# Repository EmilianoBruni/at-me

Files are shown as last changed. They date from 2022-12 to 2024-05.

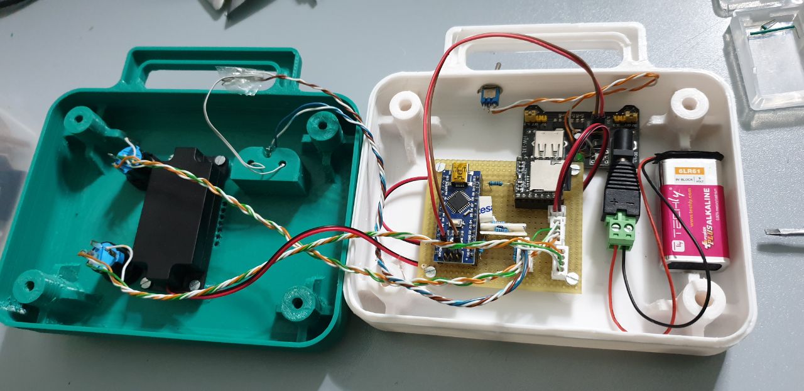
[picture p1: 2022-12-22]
Releases/00.01/photo_2022-12-22_20-16-52.jpg

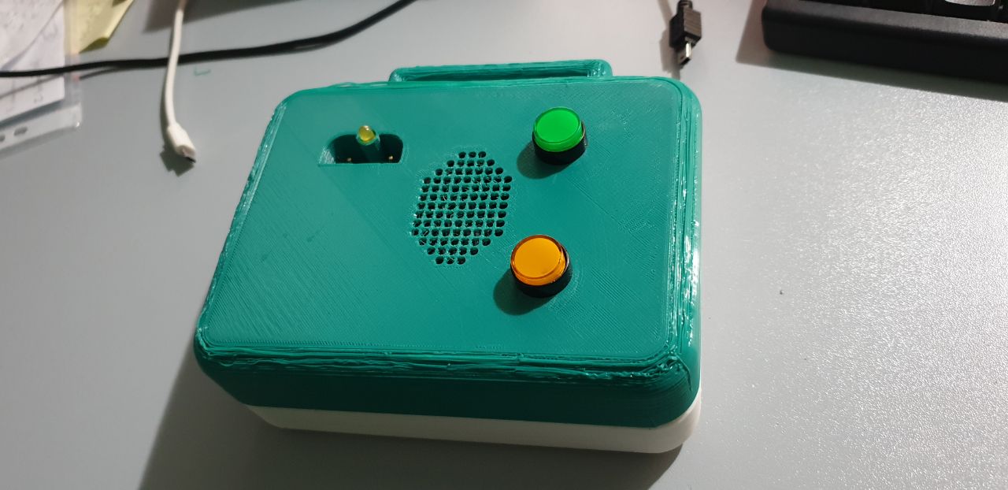
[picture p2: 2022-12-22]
Releases/00.01/photo_2022-12-22_20-16-48.jpg

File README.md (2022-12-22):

# at-me - AED Trainer made easy

## Build an AED trainer by youself

This is a hands made AED Trainer build with 

- Arduino nano, 
- DFPlayer Mini from DFRobot 
- some minor components.

The circuit is developed using Fritzing and is powered by a 9V battery, the code with Visual Code, the box with Autodesk Fusion 360 and printed with a Geeetek A20.

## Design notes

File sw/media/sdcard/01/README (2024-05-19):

Created with https://ttsfree.com/text-to-speech/italian, TTS Server 2, 100 Italian - Female - (Isabella), Voice Pitch -5%, Speed 0

02 - 1 sec@1800Hz CB128k Amplitude 0.3
10 - Applicare le placche sul torace nudo del paziente
11 - Collegare il connettore delle placche vicino la spia lampeggiante
12 - Analisi del ritmo cardiaco in corso, non toccare il paziente
13 - Scarica non consiglia, se necessario continuare con la rianimazione cardio polmonare
14 - Scarica consigliata. Carica in corso.
15 - Erogare la scarica adesso. Premere il pulsante arancione (repeated 4 times) (mix with 16)
16 - 60 sec@1800Hz CB128k Amplitude 0.1
18 - Scarica erogata
19 - Pulsante di scarica non premuto. Scarica annullata.
20 - Scarica non necessaria.
25 - Applicare le placche e dopo inserire il connettore
26 - Premere con decisione le placche sul torace nudo del paziente e dopo inserire il connettore saldamente
98 - 0.15 sec@2000Hz CB128k Amplitude 0.3
99 - In pausa. Se necessario, ricominciare con la rianimazione cardiopolmonare.

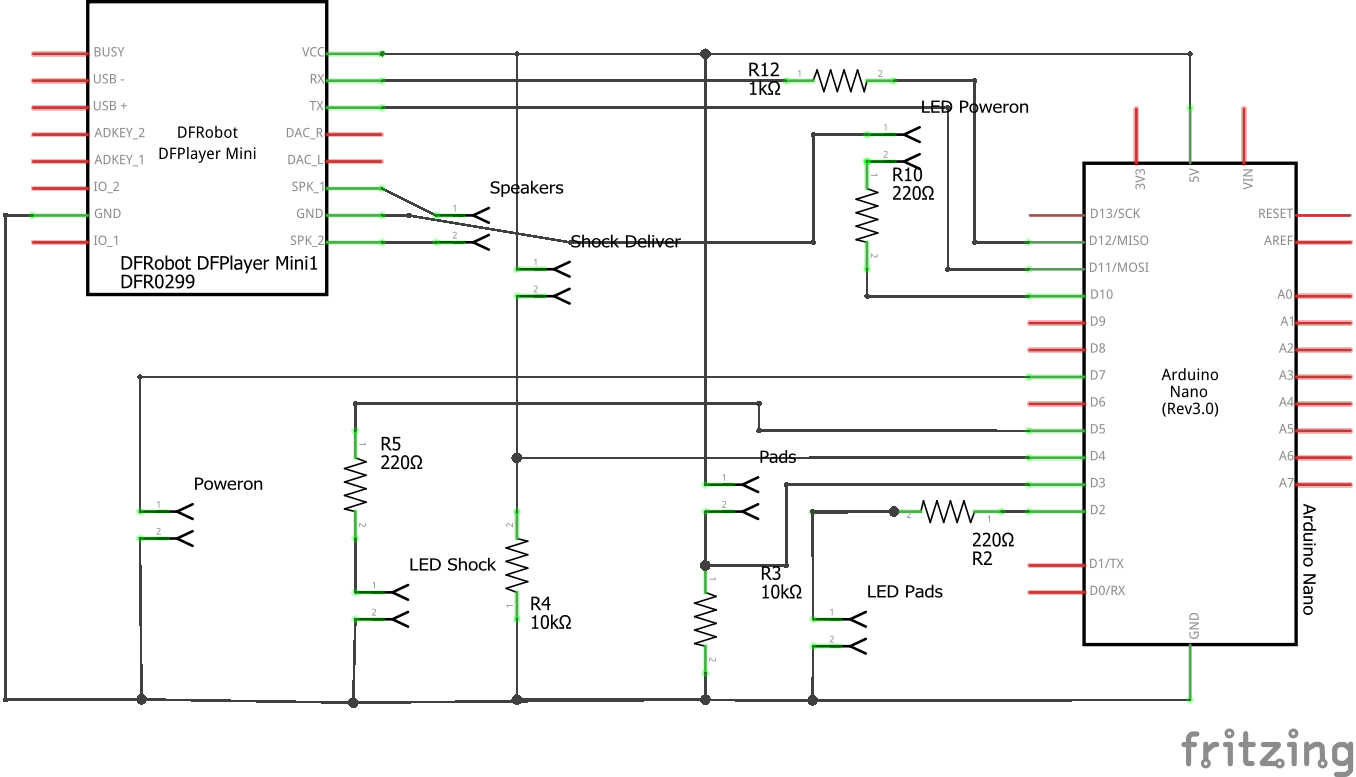
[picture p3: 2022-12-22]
Releases/00.01/schema.png

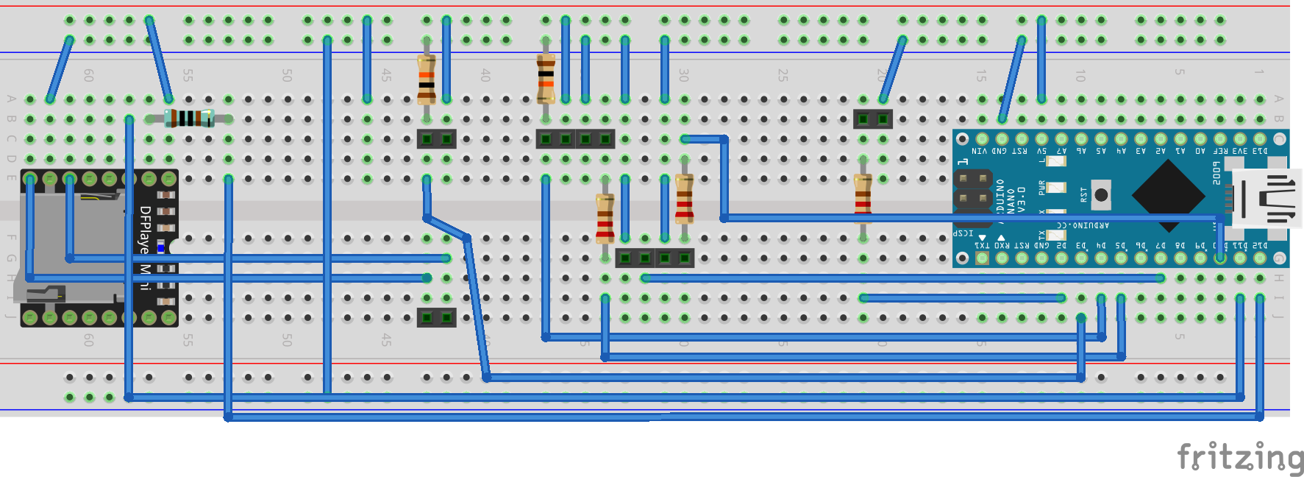
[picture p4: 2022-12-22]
Releases/00.01/breadboard.png

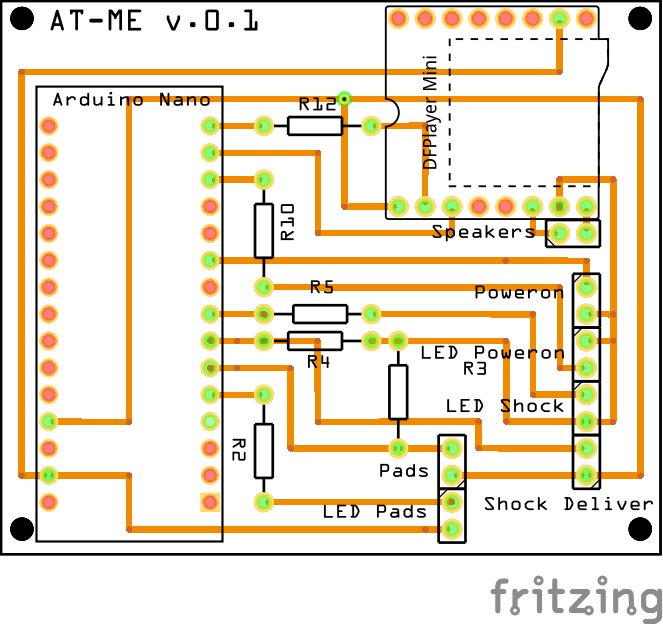
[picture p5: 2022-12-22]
Releases/00.01/pcb.png

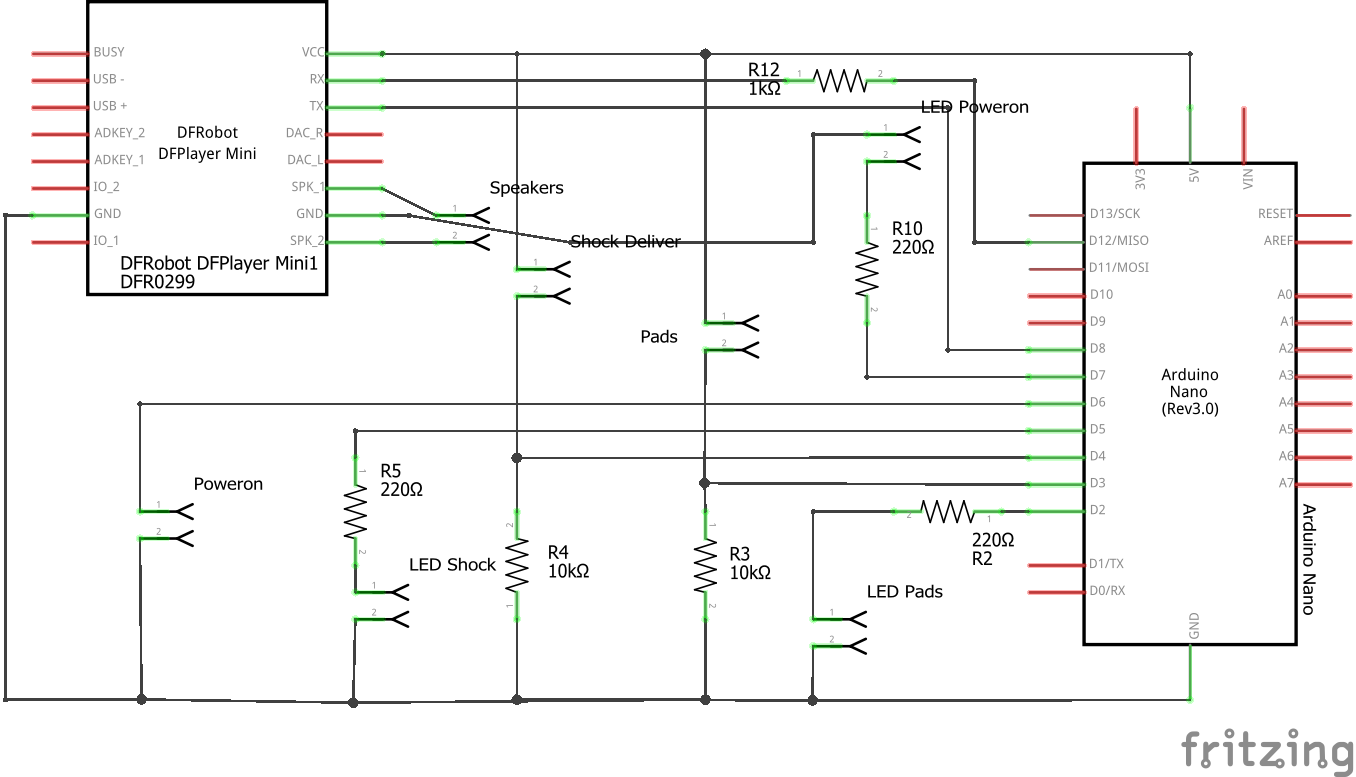
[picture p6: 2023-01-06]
Releases/00.02/schema.png

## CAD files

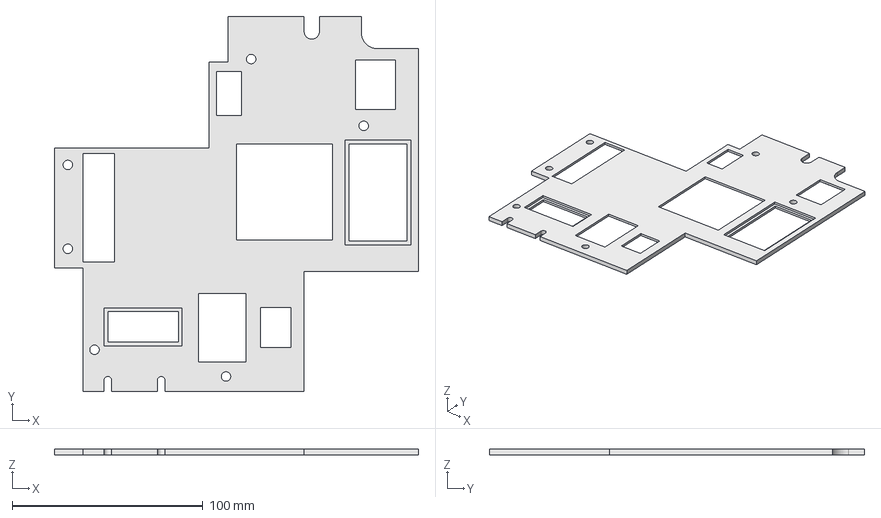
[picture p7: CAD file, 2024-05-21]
cad/Laerdal FR2 Trainer - PCB.FCStd
191.0 x 197.0 x 3.00 mm

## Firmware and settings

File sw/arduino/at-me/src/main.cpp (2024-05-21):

#include <Arduino.h>
#include <SoftwareSerial.h>
#include <DFRobotDFPlayerMini.h>
#include <Aed.h>
#include <Admin.h>
#include <OneButton.h>

#define APP_NAME           "at-me"
#define APP_VER_MAJOR      0
#define APP_VER_MINOR      6

#define SND_LANG_IT        1
#define TEST_BOARD         false
#define PADS_LED_ID        2
#define PADS_BTN_ID        3
#define SHOCK_BUTTON_ID    4
#define SHOCK_LED_ID       5
#define POWER_BUTTON_ID    6
#define POWER_LED_ID       7
#define SW_SERIAL_RX_ID    8
// in old PCB version < 0.6, TX is 12, in new PCB version, TX is 9
#define SW_SERIAL_TX_ID    APP_VER_MINOR < 6 ? 12 : 9
// in PCB version 0.5, SETUP_TOP_BTN_ID is 9, in new PCB version, SETUP_TOP_BTN_ID is 10
#define SETUP_TOP_BTN_ID   APP_VER_MINOR == 5 ? 9 : 10
// in PCB version 0.5, SETUP_BTM_BTN_ID is 10, in new PCB version, SETUP_BTM_BTN_ID is 11
#define SETUP_BTM_BTN_ID   APP_VER_MINOR == 5 ? 10 : 11

#define BTN_POWER          0
#define BTN_PADS           1
#define BTN_SHOCK          2
#define BTN_SETUP_TOP      3
#define BTN_SETUP_BTM      4

#define POWER_BUTTON_DELAY 500 // press powerButton for 0.5s
//const int           DEBUG_LED_ID       = LED_BUILTIN;


void serialInit();
void digitalInputInit();
void buttonInit();
void buttonLoop();
void powerStateUpdate();
void playerInit();
void aedInit();
void adminInit();
byte getLang();
void testBoard();

//bool                powerState = false; // AED is on/off
bool                audioState = false; // player well initialized?

SoftwareSerial      mSwSerial(SW_SERIAL_RX_ID,SW_SERIAL_TX_ID);
DFRobotDFPlayerMini mPlayer;
Aed*                mAed;
Admin*              mAdmin;
OneButton           mButtons[5];

void setup() {
    serialInit();
    digitalInputInit();
    buttonInit();   // setup OneButton buttons support
    playerInit();
    aedInit();
    adminInit();
    if (TEST_BOARD) {
        Serial.println("Test Board Mode ON");
    }
}

void loop() {
    buttonLoop();
    if (TEST_BOARD) {
        testBoard();
        return;
    }
    powerStateUpdate();
    if (mAed->getState() > PowerOff) {
        mAed->loop();
    }  else {
        // this is required to allow setVolume buttons (setup_top an setup_btm) to work
        if (mPlayer.available()) { mPlayer.readType(); }
    }
    if (mAdmin->getState() > PowerOff) mAdmin->loop();
}

void aedInit() {
    mAed = new Aed(getLang(), mPlayer, POWER_LED_ID, PADS_BTN_ID,PADS_LED_ID,
                   SHOCK_BUTTON_ID,SHOCK_LED_ID);
}

void adminInit() {
    mAdmin = new Admin(getLang(), mPlayer);
}


void serialInit() {
    Serial.begin(115200);

    Serial.println();
    Serial.println("This is " + String(APP_NAME) + " ver. " + APP_VER_MAJOR +
                   '.' + APP_VER_MINOR +
                   " - Copyright (c) 2022 - Emiliano Bruni <info@ebruni.it>");
}

void digitalInputInit() {
    // TODO: Remove after full implementation of OneButton
    pinMode(POWER_BUTTON_ID, INPUT_PULLUP);
    pinMode(SHOCK_BUTTON_ID, INPUT_PULLUP);
    pinMode(PADS_BTN_ID, INPUT_PULLUP);

    pinMode(POWER_LED_ID, OUTPUT);
    pinMode(PADS_LED_ID, OUTPUT);
    pinMode(SHOCK_LED_ID, OUTPUT);
}

void buttonInit() {
    mButtons[BTN_POWER] = OneButton(POWER_BUTTON_ID, true, true);
    mButtons[BTN_POWER].attachClick([]() {
        Serial.println("Power Button Clicked");
    });
    mButtons[BTN_POWER].attachDoubleClick([]() {
        Serial.println("Power Button Double Clicked");
    });
    mButtons[BTN_POWER].attachLongPressStart([]() {
        Serial.println("Power Button Long Press Start");
    });
    mButtons[BTN_POWER].attachLongPressStop([]() {
        Serial.println("Power Button Long Press Stop");
    });

    mButtons[BTN_PADS] = OneButton(PADS_BTN_ID, false, false);
    mButtons[BTN_PADS].attachClick([]() {
        Serial.println("Pads Button Clicked");
    });
    mButtons[BTN_PADS].attachDoubleClick([]() {
        Serial.println("Pads Button Double Clicked");
    });
    mButtons[BTN_PADS].attachLongPressStart([]() {
        Serial.println("Pads Button Long Press Start");
    });
    mButtons[BTN_PADS].attachLongPressStop([]() {
        Serial.println("Pads Button Long Press Stop");
    });

    mButtons[BTN_SHOCK] = OneButton(SHOCK_BUTTON_ID, true, true);
    mButtons[BTN_SHOCK].attachClick([]() {
        Serial.println("Shock Button Clicked");
    });
    mButtons[BTN_SHOCK].attachDoubleClick([]() {
        Serial.println("Shock Button Double Clicked");
    });
    mButtons[BTN_SHOCK].attachLongPressStart([]() {
        Serial.println("Shock Button Long Press Start");
    });
    mButtons[BTN_SHOCK].attachLongPressStop([]() {
        Serial.println("Shock Button Long Press Stop");
    });

    // one button for SETUP_TOP_BTN_ID
    mButtons[BTN_SETUP_TOP] = OneButton(SETUP_TOP_BTN_ID, true, true);
    mButtons[BTN_SETUP_TOP].attachClick([]() {
        Serial.println("Setup Top Button Clicked");
    });
    mButtons[BTN_SETUP_TOP].attachDoubleClick([]() {
        Serial.println("Setup Top Button Double Clicked");
    });
    mButtons[BTN_SETUP_TOP].attachLongPressStart([]() {
        Serial.println("Setup Top Button Long Press Start");
    });
    mButtons[BTN_SETUP_TOP].attachLongPressStop([]() {
        Serial.println("Setup Top Button Long Press Stop");
    });

    mButtons[BTN_SETUP_TOP].attachClick([]() {
        if (mAed->getState() == PowerOff) {
            mAdmin->volumeUp();
        }
    });

    // one button for SETUP_BTM_BTN_ID
    mButtons[BTN_SETUP_BTM] = OneButton(SETUP_BTM_BTN_ID, true, true);
    mButtons[BTN_SETUP_BTM].attachClick([]() {
        Serial.println("Setup Bottom Button Clicked");
    });
    mButtons[BTN_SETUP_BTM].attachDoubleClick([]() {
        Serial.println("Setup Bottom Button Double Clicked");
    });
    mButtons[BTN_SETUP_BTM].attachLongPressStart([]() {
        Serial.println("Setup Bottom Button Long Press Start");
    });
    mButtons[BTN_SETUP_BTM].attachLongPressStop([]() {
        Serial.println("Setup Bottom Button Long Press Stop");
    });

    mButtons[BTN_SETUP_BTM].attachClick([]() {
        if (mAed->getState() == PowerOff) {
            mAdmin->volumeDown();
        }
    });


}

void buttonLoop() {
    for (int i = 0; i < 5; i++) {
        mButtons[i].tick();
    }
}

void testBoard() {
    // mPlayer.volume(10);
    // mPlayer.playFolder(SND_LANG_IT, 2); // BEEP
    // loop through POWER_LED_ID, SHOCK_LED_ID, PADS_LED_ID
    int leds[3] = {POWER_LED_ID, SHOCK_LED_ID, PADS_LED_ID};
    for (int i = 0; i < 3; i++) {
        digitalWrite(leds[i], HIGH);
    }
    delay(2000);
    for (int i = 0; i < 3; i++) {
        digitalWrite(leds[i], LOW);
    }
    delay(2000);
}

void powerStateUpdate() {
    // last applied button state
    static int           lastApplied      = HIGH;
    // last readed button state
    static int           lastRead         = LOW;
    // last time button state changed
    static unsigned long lastChangingTime = 0;

    // read powerButton
    int current = digitalRead(POWER_BUTTON_ID);

    // If the switch changed, due to noise or pressing:
    if (current != lastRead) {
        // reset the debouncing timer
        lastChangingTime = millis();
    }

    // If the switch changed for almost time
    if ((millis() - lastChangingTime) > POWER_BUTTON_DELAY) {
        if (current != lastApplied) {
            lastApplied = current;
            if (current == LOW) {
                // press poweron/off
                int shockButton = digitalRead(SHOCK_BUTTON_ID);
                Serial.println("mAed state: " + String(mAed->getState()));
                Serial.println("mAdmin state: " + String(mAdmin->getState()));
                Serial.println("Shock button: " + String(shockButton));
                if (mAed->getState() == PowerOff && mAdmin->getState() == PowerOff) {
                    if (shockButton == LOW) {
                        // shock Button not pressed, normal mode,  AED poweron
                        mAed->powerOn();
                    } else {
                        // shock button pressed too, admin mode
                        mAdmin->powerOn();
                    }
                } else {
                    // AED poweroff
                    mAed->powerOff();
                    // Admin poweroff
                    mAdmin->powerOff();
                }
            }
        }
    }
    lastRead = current;
}

void playerInit() {
    mSwSerial.begin(9600);

    Serial.println(F("Initializing player... (may take 3..5 seconds)"));
    // isAck = false - https://github.com/DFRobot/DFRobotDFPlayerMini/issues/57
    audioState = mPlayer.begin(mSwSerial, false);
    if (!audioState) {
        Serial.println(F("--- ERR: Unable to initializing player"));
        return;
    }
    Serial.println(F("--- Player online"));
    mPlayer.setTimeOut(500);
}

void aedUpdate() {
}

byte getLang()
{
    return SND_LANG_IT;
}

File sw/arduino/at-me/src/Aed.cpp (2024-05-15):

#include "Aed.h"
#include <avr/wdt.h>
#include <avr/sleep.h> // Supplied AVR Sleep Macros
#include <DFRobotDFPlayerMini.h>

static int isrNextStateRequest = Invalid;       // ISR_request
static int isrNextStateApply = Invalid;         // ISR apply
static int seqProgram = PRG_TWO_SHOCK_THEN_NOT; // shock sequence program
static int seqCount = 0;                        // shock sequence count

ISR(WDT_vect)
{
    sleep_disable(); // Disable Sleep on Wakeup
    Serial.println("Inside ISR. Isr State is " + String(isrNextStateRequest));
    if (isrNextStateRequest != Invalid)
    {
        isrNextStateApply = isrNextStateRequest;
        isrNextStateRequest = Invalid;
    }
    sleep_enable(); // Enable Sleep Mode
}

Aed::Aed(byte lang, DFRobotDFPlayerMini player, byte pin_power_led, byte pin_pads, byte pin_pads_led, byte pin_shock, byte pin_shock_led)
{
    this->lang = lang;
    this->player = player;
    this->pin_power_led = pin_power_led;
    this->pin_pads = pin_pads;
    this->pin_pads_led = pin_pads_led;
    this->pin_shock = pin_shock;
    this->pin_shock_led = pin_shock_led;
    setup();
}

void Aed::setup()
{
    powerOff();

    // // ISR init (wdt_enbled/wdt_disabled is BUGGED and reset card)
    // // Set up Watch Dog Timer for Inactivity
    WDTCSR |= (_BV(WDCE) | _BV(WDE)); // Enable the WD Change Bit
    WDTCSR = _BV(WDIE) |              // Enable WDT Interrupt
             _BV(WDP2) | _BV(WDP1);   // Set Timeout to ~1 seconds
    WDTCSR = 0x00;                    // Disable the WDT
}

void Aed::setShockLed(bool to_on)
{
    digitalWrite(pin_shock_led, to_on ? HIGH : LOW);
}

void Aed::loop()
{
    checkISRState();
    flowControl();
    togglePadsLed(); // here because it's a timer
                     // loop
    toggleShockLed();
    if (player.available())
        checkPlayerStatus(player.readType(), player.read());
}

void Aed::flowControl()
{
    // here all aed flowchart logic
    static unsigned long shockTimer = 0;         // timer for shock
    static unsigned long pushButtonTimer = 0;    // timer if operator does'nt
                                                 // play shock
    static unsigned long padsConnectedTimer = 0; // timer for delay padsConn
    static unsigned long inPauseTimer = 0;

    unsigned long now = millis();

    // manage linking pads
    bool padsLinkedState = digitalRead(pin_pads);
    if (padsLinkedState == HIGH && state != PowerOff && state < PadsConnected)
    {
        if (padsConnectedTimer > 0)
        {
            // pads connected, wait for 1 sec of continuos connection
            if (now - padsConnectedTimer > 2000)
            {
                // if connected for more than 1 sec, ok, it's time to analyze
                padsConnectedTimer = 0;
                setState(PadsConnected);
            }
        }
        else
        {
            // I see pads connected for first time, start padsConnected Timer
            padsConnectedTimer = now;
        }
    }
    else if (padsLinkedState == LOW && (state == PadsNotConnected 
        || state == PadsNotConnectedAgain || state == PadsNotConnectedAgain2))
    {
        // pads connection goes up/down fast
        if (padsConnectedTimer > 0 )
        {
            // if not pads up/down fast or pads not connected for more than 1 sec
            padsConnectedTimer = 0;
        }
    }
    else if (padsLinkedState == LOW && state > PadsNotConnectedAgain2)
    {
        setState(PadsNotConnected);
        inPauseTimer = shockTimer = pushButtonTimer = 0;
    }

    // for timeouting push button state if operator does'nt push button
    if (state == PushButton && pushButtonTimer == 0)
        pushButtonTimer = now;

    // if operator does'nt push button in 40 seconds, cancel shock
    if (pushButtonTimer > 0 && now - pushButtonTimer > 40000)
    {
        shockTimer = pushButtonTimer = 0;
        setState(ShockCancelled);
        inPauseTimer = now;
    }

    // Shock not needed
    if (state == RequestPauseByShockNotNeeded) {
        shockTimer = pushButtonTimer = 0;
        setState(InPause);
        inPauseTimer = now;
    }

    if (state == PushButton)
    {
        bool ps = digitalRead(pin_shock);
        if (ps == HIGH)
        {
            shockTimer = pushButtonTimer = 0;
            setState(ShockDelivered);
            inPauseTimer = now;
        }
    }

    // 2 minutes are gone, new analysis
    if (inPauseTimer > 0 && now - inPauseTimer > 120000)
    {
        inPauseTimer = 0;
        setState(PadsConnected);
    }
}

void Aed::play(byte id)
{
    playFinishedId = SND_UNDEF;
    playStartId = id;
    player.playFolder(this->lang, id);
    Serial.print(F("Start playing "));
    Serial.println(id);
}

void Aed::powerOn()
{
    digitalWrite(pin_power_led, HIGH);
    // reset some global variables
    seqCount = 0;
    setState(PoweredOn);
}

void Aed::powerOff()
{
    digitalWrite(pin_power_led, LOW);
    digitalWrite(pin_pads_led, LOW);
    setShockLed(false);
    player.stop();
    setState(PowerOff);
}
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

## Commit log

2022-01-12 Add first diagram scheme
    [at-me.fzz]
2022-01-13 Add pads led
    [at-me.fzz]
2022-01-13 Add pads connector. AED stage till analyze stage.
    [at-me.fzz]
2022-01-14 Clear some code and solved a bug where SND_ANALYZING isn't played if poweron with pads connected
    [Aed.cpp, Aed.h, main.cpp]
2022-01-15 Congede default volume. Power button now off when program run
2022-01-15 Support for shock advise, push button request and shock cancelled if too much time as gone.
    [Aed.cpp, Aed.h]
2022-01-16 Add Shock Led
2022-01-16 Add Shock led to diagram
    [at-me.fzz]
2022-01-16 Add shock deliver code but it doesn't work well now
    [Aed.cpp]
2022-01-17 Update diagram to add shock button
    [at-me.fzz]
2022-01-19 Test to use a interrupt
2022-01-25 Update diagrams and add perfboard scheme
    [at-me-perfboard.fzz, at-me.fzz]
2022-12-04 Add PCB project
    [at-me.fzz]
2022-12-08 Now Watchdog interrupt works. Currently active in Analyzing and SchockRequired state
2022-12-08 Changed pcb
    [at-me.fzz]
2022-12-09 Change Button and Led Ids to better organize PCB
    [at-me.fzz]
2022-12-11 changes in breadboard
    [at-me.fzz]
2022-12-13 First recompact of PCB in v2
    [at-me.fzz]
2022-12-13 First commit of PCB v2
    [at-me.fzz]
2022-12-14 Add ShockNotNeeded state and correlated voice file. Add support for multiple program sequence. Currently default is 2 shock required and then no shock needed.
2022-12-22 Moved Power button and power led pin
    [at-me.fzz]
2022-12-22 More simplify pcb
    [at-me.fzz]
2022-12-25 Switch between two types of Arduino Nano
2022-12-25 Little changes in PCB label position
    [at-me.fzz]
2023-01-05 Sometimes pads doesn't a good contact. Add a delay to be sure that pads contact are stable
    [main.cpp]
2023-01-17 If power button is pressed with shock button, enter admin mode.
2024-02-08 Changed board
2024-02-08 Add OpenSCAD project for Laerdal FR2 pcb replacement
    [Laerdal FR2 Trainer - pcb shape.scad]
2024-03-09 Add diagram for laerdal replacement PCB
    [at-me - laerdal.fzz]
2024-03-09 Add cad for laerdal replacement PCB
    [Laerdal FR2 Trainer - PCB.FCStd]
2024-03-19 Add YwRobot Power Supply
    [at-me - laerdal.fzz]
2024-03-28 Update Laerdal PCB
    [Laerdal FR2 Trainer - PCB.FCStd]
2024-04-21 Optimized change state for push button and used one file for push button message and long beep to avoid bug when switch between message and beep
    [Aed.cpp]
2024-05-15 Refactor powerOn method to use PowerOn constant instead of PoweredOn
2024-05-15 Moved pin setup to main program
2024-05-15 Add a test_board function and first attempt to refactor button handling using OneButton library
2024-05-18 Update SW_SERIAL_TX_ID based on PCB version
2024-05-18 Add setup buttons implemented with OneButton
2024-05-19 Add setup_top and setup_btm function to change volume (current not saved state)
2024-05-21 Convert Laerdal FR2 Trainer PCB shape from scad to FreeCad
    [Laerdal FR2 Trainer - PCB.FCStd, Laerdal FR2 Trainer - pcb shape.scad]
2024-05-21 Shock Button is now activeLow
2024-05-21 Pads button converted to pullup mode
